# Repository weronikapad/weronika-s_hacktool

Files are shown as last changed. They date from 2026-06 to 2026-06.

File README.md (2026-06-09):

## Weronika's Hacktool

A Raspberry pi Pico based hardware tool that can be plugged in via USB-A or or a connecting wire between raspberry's pi pico and a device that you're connecting it to.

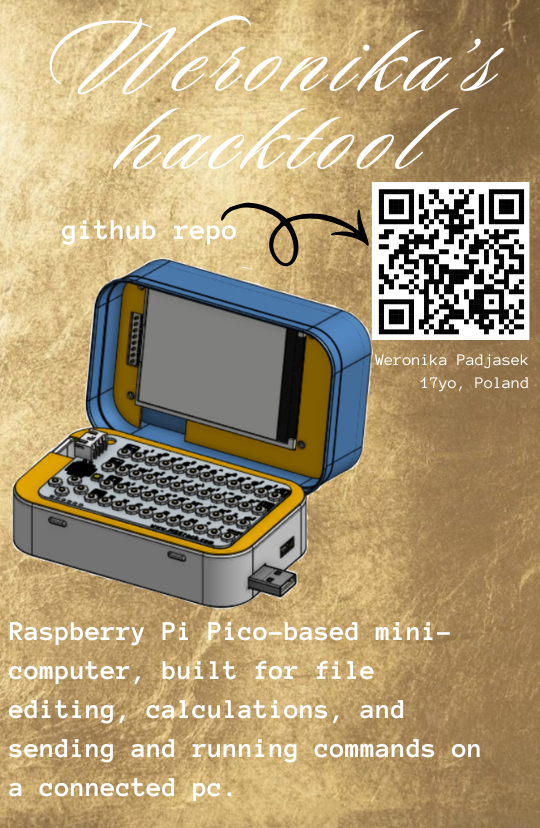
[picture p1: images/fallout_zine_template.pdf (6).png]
fallout_zine_template.pdf (6).png


## 3D model on onshape:

https://cad.onshape.com/documents/8ba63a7496dc739681835abf/w/b2486c84e183ee5c75462b5f/e/727d0ff90b4b33300ac8e23b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

## Specifics
Raspberry pi pico is powered by a LiPo battery, that is charged through USB-A and the voltage that pico receives is controled by the power manager. 
1. specifics to connecting hardware parts
   a) battery:
      - connect it with a male to male wire to a connector pin socket 01x02
   
   b) keyboard (look at connector pins on conn_01x04 from KiCad view), (use female to female wires)
     - Pin1 -> wire -> the pin in the keyboard port that the black wire from the picture goes into
     - Pin2 -> wire -> the pin in the keyboard port that the red wire from the picture goes into
     - Pin3 -> wire -> the pin in the keyboard port that the white wire from the picture goes into
     - Pin4 -> wire -> the pin in the keyboard port that the yellow wire from the picture goes into
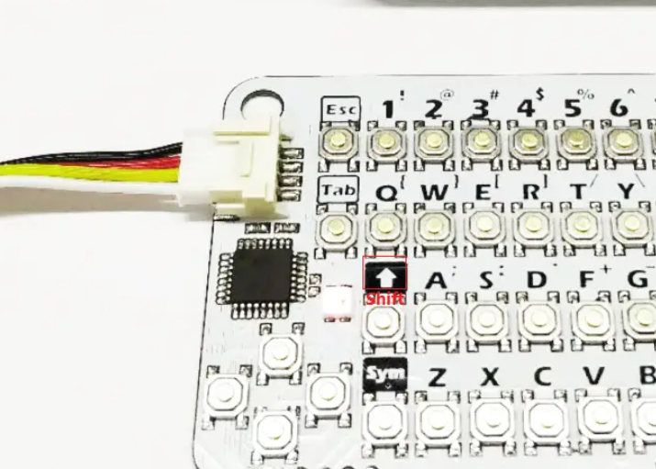
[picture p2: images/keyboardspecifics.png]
keyboardspecifics


    c) screen (use female to female wires)(look at connector pins on conn_01x09 from KiCad view)
      - Pin1 -> wire -> vcc on the screen
      - Pin2 -> wire -> GND on the screen
      - Pin3 -> wire -> CS on the screen
      - Pin4 -> wire -> SDO(MISO) on the screen
      - Pin5 -> wire -> SCK on the screen
      - Pin6 -> wire -> SDI(MOSI) on the screen
      - Pin7 -> wire -> DC on the screen
      - Pin8 -> wire -> LED on the screen

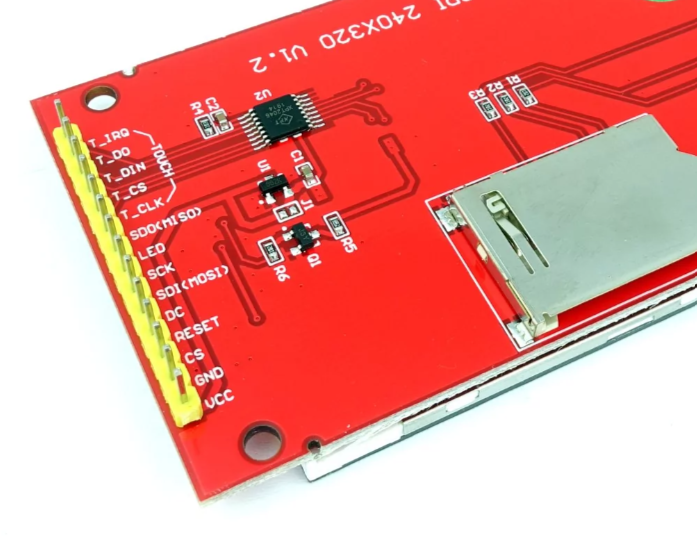
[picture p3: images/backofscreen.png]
backofscreen
  

## Features

-Raspberry pi Pico
-SD card port (microSD_HC_Molex_104031-0811)
-USB-A (USB_A_CNCTech_1001-011-01101_Horizontal)
-2000 Ohm resistor
-Power manager (TP4057)
-LCD display 
-Keyboard
-LiPo Battery
-Connectors on PCB for screen, keyboard and battery conection

## PCB 
Designed in KiCad, through pico's USB using REPL, pico can send commands to pluged pc and receive and print output, and through UART it can monitor traffic. Independently it can serve as a calculator or a text editor.

**PCB's front copper layer view in KiCad**

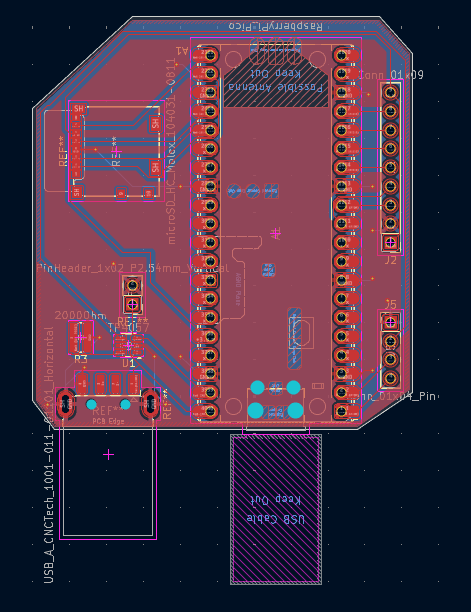
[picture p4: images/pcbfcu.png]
pcbfcu


**PCB's back copper layer view in KiCad**

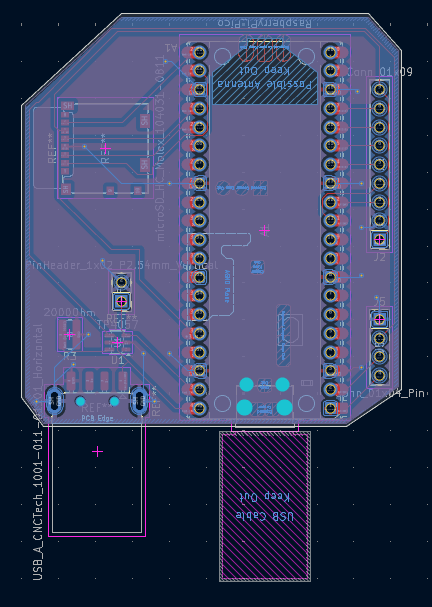
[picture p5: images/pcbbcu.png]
pcbbcu


**PCB's 3D model, with exact location of specific connectors**

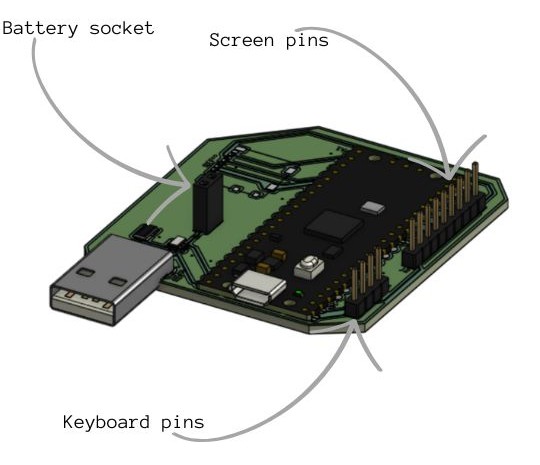
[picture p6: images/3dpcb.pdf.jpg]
3dpcb.pdf


## Schematic

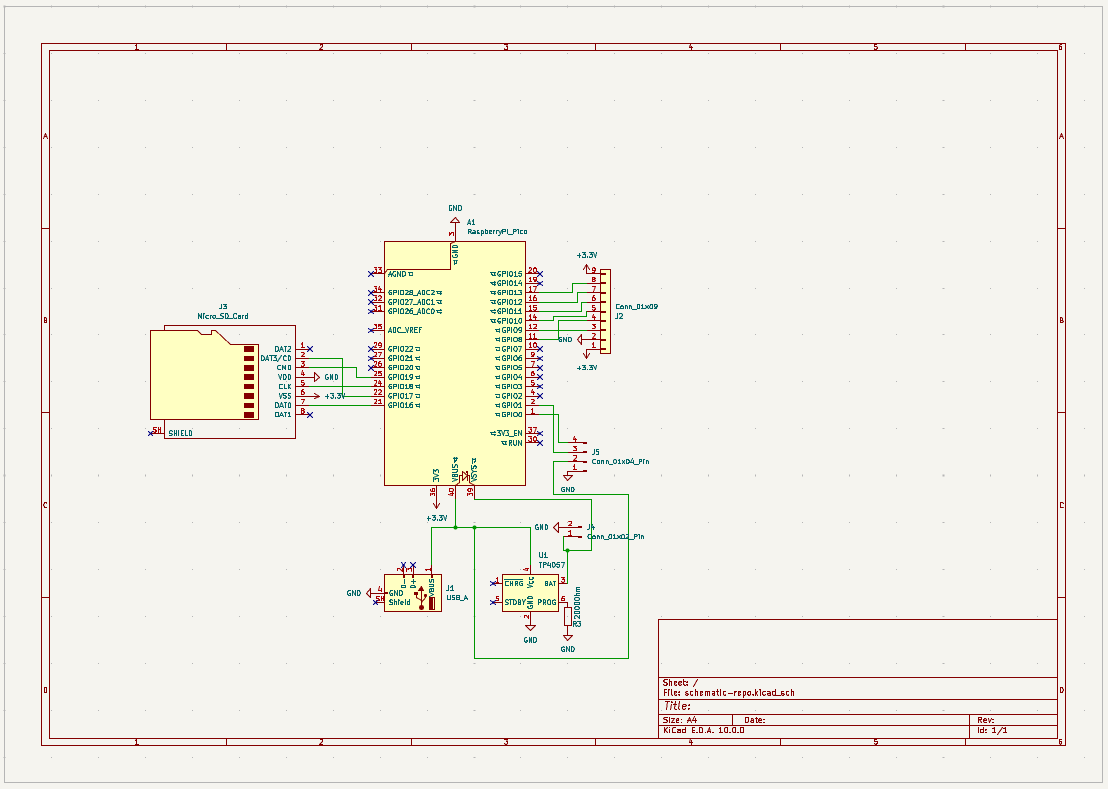
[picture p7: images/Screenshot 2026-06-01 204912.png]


## detailed description on how to use

1. download firmware for pico, and pc
2. download Thonny
3. works best with an sd card connected
4. before assembling everything in the box:
   - plug raspberry pico via wire to your pc
   - push firmware files onto pico
5. to stop any program at any time press esc
6. in order to use the REPL program, or UART:
   - connect pico to at least the screen, and and keyboard
   a) for REPL:
      - in the terminal type "repl"
      - then type the command that you wish to run in your pluged device
     - pico is programed to always run in administrator mode in your pc's cmd so, in order for the rogram to run as intended you must allow it on your pc
    b) for UART:
      -in the terminal type "uart"
7. to use the hacktool independently:
   - connect the pcb to keyboard, screen, and battery
   - charge the battery via USB-A
   a) to use the text editor:
      - type in the terminal "text" + your filename (it can be already saved on sd card or can be created by this command)
        if the file exists:
          - to edit the file type "edit"
          - to delete type "delete"
          - if you change your mind and you no longer wish to engage with the text editor type "leave"
        if it doesn't:
          - type "create" to create it and open it
          - type "leave" if you don't wish to create
8. if you forgot any of those commands type "help" in the main terminal

## why i build this:
I wanted to understand computers and cybersecurity better, i specifically used REPL as i thought it is one of the most universal hacking abilites of raspberry pi pico, I first decided uppon pico because it was all over my feed on tiktok but as it actually turns out it was the perfect fit for my project

## credits:
image from the magazine page, originally distributed by kylatcarter on pinterest: https://pl.pinterest.com/pin/1135399756078582773/ 
readme structure inspired by notaroomba from github

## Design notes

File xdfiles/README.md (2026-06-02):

## Weronika's Hacktool

A raspberry pi Pico based hardware tool that can be pluged via USB-A or or a connecting wire betwen raspberry's pi pico and a device that you're connecting it to.

## Features

-Raspberry pi Pico
-SD card port (microSD_HC_Molex_104031-0811)
-USB-A (USB_A_CNCTech_1001-011-01101_Horizontal)
-2000 Ohm resistor
-Power manager (TP4057)
-LCD display 
-Keyboard
-LiPo Battry
-Connectors on PCB for screen, keyboard and battery conection

## PCB 
Designed in KiCad, through pico's USB using REPL, pico can send comand to pluged pc, and through UART it can monitor trafic. Independently it can serve as a calculator or a text editor.

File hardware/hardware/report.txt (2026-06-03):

Info: X scale constrained.
Info: Y scale constrained.
Warning: Width correction constrained.  The width correction value must be in the range of [0.000001 mm; 0.199999 mm] for the current design rules.
Plotted to 'C:\Users\Lenovo\Downloads\gerber\hardware-F_Cu.gbr'.
Plotted to 'C:\Users\Lenovo\Downloads\gerber\hardware-B_Cu.gbr'.
Plotted to 'C:\Users\Lenovo\Downloads\gerber\hardware-F_Paste.gbr'.
Plotted to 'C:\Users\Lenovo\Downloads\gerber\hardware-B_Paste.gbr'.
Plotted to 'C:\Users\Lenovo\Downloads\gerber\hardware-F_Silkscreen.gbr'.
Plotted to 'C:\Users\Lenovo\Downloads\gerber\hardware-B_Silkscreen.gbr'.
Plotted to 'C:\Users\Lenovo\Downloads\gerber\hardware-F_Mask.gbr'.
Plotted to 'C:\Users\Lenovo\Downloads\gerber\hardware-B_Mask.gbr'.
Plotted to 'C:\Users\Lenovo\Downloads\gerber\hardware-Edge_Cuts.gbr'.
Created Gerber job file 'C:\Users\Lenovo\Downloads\gerber\hardware-job.gbrjob'.
Info: Done.

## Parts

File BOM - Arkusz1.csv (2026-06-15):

Item | Cost | Link | Quantity
Raspberry Pi Pico | 4.94 USD | https://botland.com.pl/moduly-i-zestawy-do-raspberry-pi-pico/18767-raspberry-pi-pico-rp2040-arm-cortex-m0-0617588405587.html | 1
Micro SD card | 2.56 USD | https://pl.farnell.com/molex/104031-0811/connector-micro-sd-8pos/dp/2678573 | 1
USB_A | 0.86 USD | https://www.digikey.pl/pl/products/detail/cnc-tech/1001-011-01101/3064739 | 1
TP4057 power manager | 0.82 USD | https://allegro.pl/produkt/tp4057-battery-charger-1af03e5b-a3f5-4e60-a73b-e6587dc6ee7f?offerId=17890124524 | 1
Keyboard CardKB V1.1 ATmega8A | 10.63 USD | https://botland.com.pl/moduly-unit-moduly-rozszerzen/21897-mini-klawiatura-keyboard-cardkb-v11-atmega8a-modul-rozszerzen-unit-do-modulow-deweloperskich-m5stac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 | 1
PIN HEADER 1x40 | 1.64 USD | https://allegro.pl/produkt/zlacze-szpilkowe-pin-header-1x40-h-30mm-rm-2-54mm-7a350a7e-0498-4583-8c29-9f037f3ad1fc?offerId=7931790327 | 1
Dissplay LCD 2.8" 320x240px ST7789 SPI | 10.63 USD | https://elektroweb.pl/pl/wyswietlacze-lcd/1285-wyswietlacz-lcd-28-240x320-st7789-spi-dotykowy-slot-microsd.html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 | 1
LiPo 1000mAh 3.7V battery | 6.26 USD | https://botland.com.pl/akumulatory-li-pol-1s-37v/15613-akumulator-li-pol-akyga-1000mah-1s-37v-zlacze-jst-bec-gniazdo-48x30x7mm-5904422324230.html | 1
Male to male wire (for the battery) | 1.18 USD | http://abc-rc.pl/pl/products/przewody-kable-zworki-dupont-m-m-40-szt-10cm-mesko-meskie-18982.html | 1
Female to female wire (for keyboard and screen) | 1.35 USD | https://botland.com.pl/przewody-polaczeniowe-zensko-zenskie/19948-przewody-polaczeniowe-zensko-zenskie-justpi-10cm-40szt-5904422328672.html | 1
PCB | 66 USD | https://aisler.net/e3iji2-your-account/sandbox/hardware/order/new?service=beautiful_boards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 | 1
Total | 106.87 USD |  | 11

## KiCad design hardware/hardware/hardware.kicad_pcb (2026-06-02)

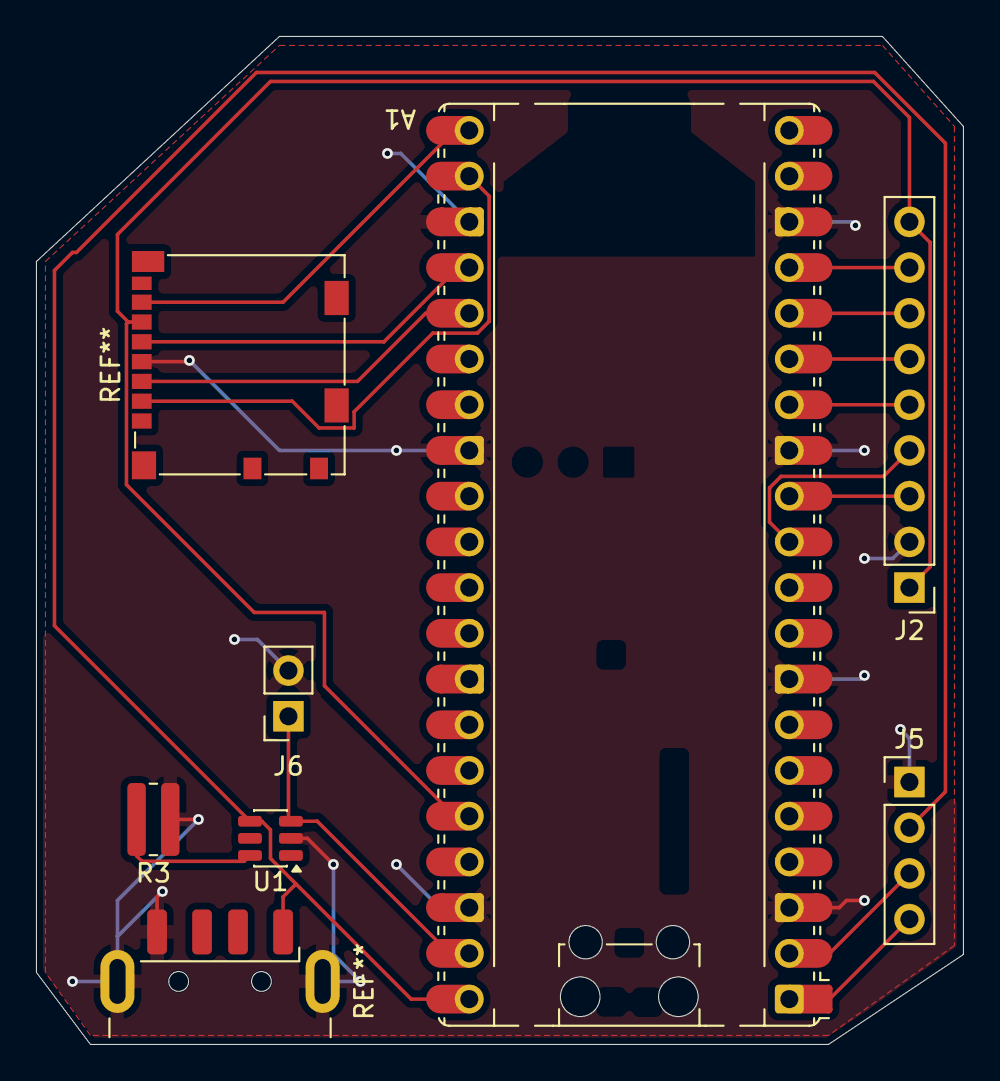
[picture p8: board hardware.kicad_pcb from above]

Board: 2 copper layers, 51.5 x 56.0 mm, 6 parts (0 on the bottom side), 13 nets.

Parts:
A1: RaspberryPi_Pico; RaspberryPi_Pico_Common_Unspecified
J2: Conn_01x09; PinHeader_1x09_P2.54mm_Vertical
J5: Conn_01x04_Pin; PinHeader_1x04_P2.54mm_Vertical
J6: Conn_01x02; PinSocket_1x02_P2.54mm_Vertical
R3: 2000Ohm; R_0815_2038Metric
U1: TP4057; TSOT-23-6

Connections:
+3.3V: A1.36 (3V3), J2.1, J2.9
GND: A1.3 (GND), A1.8 (GND), A1.13 (GND), A1.18 (GND), A1.23 (GND), A1.28 (GND), A1.38 (GND), J2.2, J5.1, J6.2, R3.1, U1.2 (GND)
unnamed: A1.1 (GPIO0), J5.4
unnamed: A1.2 (GPIO1), J5.3
unnamed: A1.11 (GPIO8), J2.4
unnamed: A1.12 (GPIO9), J2.3
unnamed: A1.14 (GPIO10), J2.5
unnamed: A1.15 (GPIO11), J2.6
unnamed: A1.16 (GPIO12), J2.7
unnamed: A1.17 (GPIO13), J2.8
unnamed: A1.40 (VBUS), J5.2, U1.4 (V_{CC})
unnamed: A1.39 (VSYS), J6.1, U1.3 (BAT)
unnamed: R3.2, U1.6 (PROG)

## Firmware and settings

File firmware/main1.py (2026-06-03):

from machine import Pin, SPI, I2C
import ili9341
import time
import os

i2c = I2C(0, sda = Pin(0), scl = Pin(1), freq = 400000)
spi = SPI(1, baudrate = 40000000, sck = Pin(10), mosi = Pin(11), miso = Pin(8))
screen = ili9341.Display(spi, dc=Pin(12), cs=Pin(9), rst=Pin(13))



while True:

    def show(text):
        show("type a command/help: :")
        display.clear(ili9341)
        lines = text.split("\n")
        for i, line in enumerate(lines):
            display.draw_text(10, 10 + i * 20, line, ili9341)
        
            def get_input():
                typed = ""
                show(typed)
                while True:
                    k = i2c.readfrom(0x5F, 1).decode("uft-8")
                    if k == "\r":
                        return(typed)
                    elif k == "\x1b":
                        return "esc"
                    elif k == "\x08":
                        typed = typed[:-1]
                    elif k !="\x00":
                        typed += k
                    show(typed)
        
            show("terminal\ntype help")
            time.sleep(1)
        
            while True:
                show("type command")
                user = get_input().lower()
            
                if user == "uart":
                    import uart
                    uart.run(show, get_input)
            
                elif user == "repl":
                    import REPL
                    REPL.run(show, get_input)
                
                elif user == "calc":
                    import calc
                    calc.run(show, get_input)
                
                elif user.startswith("text "):
                    filename = user.split("")[1]
                    
                    try:
                        open(filename, 'r').close()
                        show(filename + "\n edit/delete/leave")
                        command = get_input()
                    
                        if command == "edit":
                            import text
                            text.run(show, get_input, filename)
                        elif command == "delete":
                            os.remove(filename)
                            show("deleted")
                        elif command == "leave":
                            pass
                        else:
                            show("command not valid")
                            pass
            
                    except:
                        show(filename + "\n create/leave")
                        command = get_input()
                        if command == "create":
                            import text
                            text.run(show, get_input, filename)
                        elif command == "leave":
                            pass
                        
        
                
                elif user == "help":
                    show("uart \n REPL \n calc \n text")
                    time.sleep(2)
                
                elif user == "esc":
                    pass
            
                else:
                    show("unknown command: " + user)
                
                

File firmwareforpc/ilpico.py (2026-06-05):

import serial
import subprocess
import ctypes
import sys

print("running")
def admin():
    try:
        return ctypes.windll.shell32.IsUserAdmin()
    except:
        return False
if not admin():
    ctypes.windll.shell32.ShellExecuteW(    None, "runas", sys.executable, " ".join(sys.argv), None, 1)
    sys.exit()

from serial.tools import list_ports

def find_pico():
    ports = list_ports.comports()
    for port in ports:
        if "RP2040" in port.description or "USB Serial" in port.description:
            return port.device
    return None
port = find_pico()

if port is None:
    print("pico not found")
    sys.exit()
else:
    print("pico on: " + port)


pico = serial.Serial(port, 115200)
# rfc2217ServerPort = 4000

print("type command on pico")

while True:
    textplsc = pico.read() #raw
    textplsc = textplsc.decode().strip()
    print("picoinput: " + textplsc)

    if textplsc.startswith("cmd: "):
        cmd = textplsc[5:]
        if cmd.startswith("fech "):
            filename = cmd.split(" ")[1]
            try:
                f = open(filename, "r")
                data = f.read()
                f.close()
                pico.write(data.encode())
            except:
                pico.write((filename + " not found").encode())
    else:
        result = subprocess.run(cmd, shell = True, capture_output = True, text = True )
        output = result.stdout
        if output == "":
            output = result.stderr
        pico.write(output.encode())

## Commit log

2026-06-01 rest of my files
    [BOM.csv, hardware.kicad_pcb, hardware.kicad_sch]
2026-06-02 xd
    Corrected typos in wiring instructions and updated images.
2026-06-03 ahhhhhhhhh
    Correct formatting for battery connection instructions.
